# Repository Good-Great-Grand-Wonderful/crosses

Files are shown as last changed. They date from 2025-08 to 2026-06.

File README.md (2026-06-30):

> [!NOTE]
> This repo is for historical purposes. Crosses has iterated and is now on [V2](https://github.com/Good-Great-Grand-Wonderful/crosses-v2)

# Crosses
_DSF2417

### Gerbers

Production ready and prepped with JLCPCB part numbers: [Gerbers](Gerbers)

### BOM

#### Cases

N = Number of trackballs

| Qty |3x5 | 3x6 | 4x6 | Item | Notes |
|---|----|-----|-----|---|---|
| 24 | x  | x | x | M3 Heat set inserts | |
| 16 | x  | x | x | M3 x 5mm Hex Bolts | +2 for every trackball you delete |
| 2xN | x  | x | x | M3 x 12mm Hex Bolts | |
| 2xN | x  | x | x | M3 x 8mm Hex Bolts | |
| 1 | x  | x | x | Thumb Cluster PCB Panel | |
| 4 | x  | x | x | Hirose FH12-14S 0.5SH 1x14 1MP P0.50mm Horizontal | |
| 2 | x  | x | x | SM06B-SRSS-TB(LF)(SN) | |
| 1 | x  | | | 3x5 Matrix PCB Panel | |
| 1 | | x | | 3x6 Matrix PCB Panel | |
| 1 | | | x | 4x6 Matrix PCB Panel | |
| 2 | x  | x | x | 150mm 14p 0.5mm pitch FFC cables | |
| 1xN | x  | x | x | 100mm 6p JST SH 1.0 Same direction cables | |
| 2x | x  | x | x | Thumb Cluster Case (one should be flipped) | |
| 2x | x  | | | 3x5 Matrix Case (one should be flipped) | |
| 2x | | x | | 3x6 Matrix Case (one should be flipped) | |
| 2x | | | x | 4x6 Matrix Case (one should be flipped) | |
| 36x | x  | | | Kailh Choc Hotswap Sockets | |
| 42x | | x | | Kailh Choc Hotswap Sockets | |
| 54x | | | x | Kailh Choc Hotswap Sockets | |
| 36x | x  | | | 1N4148 SMD SOD-123 Resistors | |
| 42x | | x | | 1N4148 SMD SOD-123 Resistors | |
| 54x | | | x | 1N4148 SMD SOD-123 Resistors | |
| 2 | x  | x | x | Trackball Mount | `models` directory |
| 1xN | x  | x | x | Trackball PCB | |
| 1xN | x  | x | x | PMW3610 | |
| 1xN | x  | x | x | Trackball Carrier Base | `models` directory |
| 1xN | x  | x | x | Trackball Carrier Top | `models` directory |

## License



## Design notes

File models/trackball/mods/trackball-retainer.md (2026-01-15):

# Trackball Retainer

## Description
A trackball retainer mod for the Crosses/Bridges keyboards.

## Compatibility
- **Status:** Only tested with the **Bridges** variant.

## Bill of Materials (BOM)
- **Bearings:** 6x 2.8mm diameter bearings.
  - *Note:* 3mm bearings may work but have not been tested.
- **Heat Inserts:** 
  - Hole requires a **4.4mm** diameter heat insert (slightly larger than the standard ones used for Crosses/Bridges).

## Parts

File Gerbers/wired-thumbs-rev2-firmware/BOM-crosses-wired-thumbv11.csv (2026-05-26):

Comment | Designator | Footprint | LCSC | Quantity
SM06B-SRSS-TB(LF)(SN) | J1,J2 | SM06B-SRSS-TB(LF)(SN) | C160405 | 2
TYPE-C-31-M-12 USB | P1,P2 | USB_C_Receptacle_HRO_TYPE-C-31-M-12 | C165948 | 2
Conn_01x14_Pin | J4,J5 | Hirose_FH12-14S-0.5SH_1x14-1MP_P0.50mm_Horizontal | C5378715 | 2
1N4148 | D1,D2,D3,D4,D5,D6 | D_SOD-123 | C81598 | 6
MountingHole | H3 | MountingHole_3.2mm_M3_DIN965_Pad |  | 1
MountingHole | H1 | MountingHole_3.2mm_M3_DIN965_Pad |  | 1
MountingHole | H2 | MountingHole_3.2mm_M3_DIN965_Pad |  | 1

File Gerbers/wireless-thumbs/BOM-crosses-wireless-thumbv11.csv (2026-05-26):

Comment | Designator | Footprint | LCSC | Quantity
SM06B-SRSS-TB(LF)(SN) | J1,J2 | JST_SH_SM06B-SRSS-TB_1x06-1MP_P1.00mm_Horizontal | C160405 | 2
Conn_01x14_Pin | J4,J5 | XUNPU_FPC-05F-14PH20_1x14-1MP_P0.5mm_Horizontal | C2856800 | 2
1N4148 | D1,D2,D3,D4,D5,D6 | D_SOD-123 | C81598 | 6

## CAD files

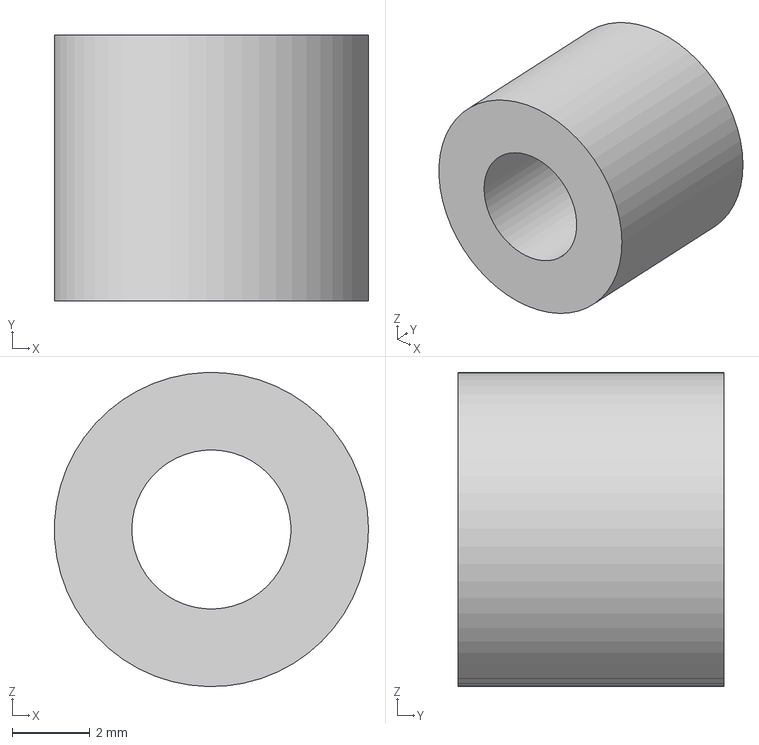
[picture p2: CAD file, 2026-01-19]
models/experiments/adjustable/adjustable-mount-spacer.step
8.09 x 6.86 x 8.10 mm

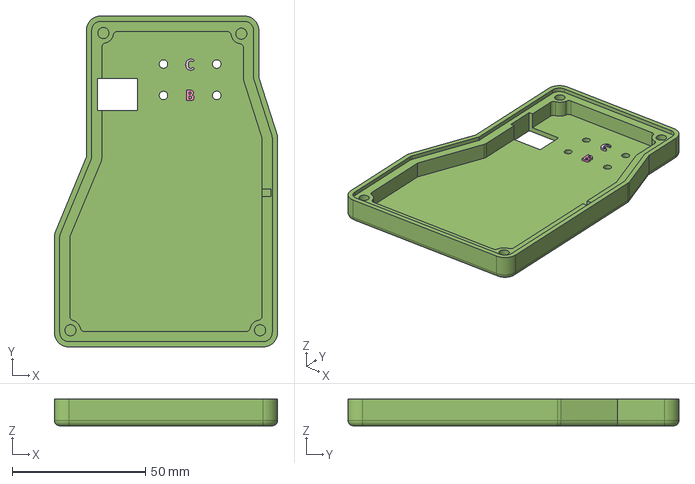
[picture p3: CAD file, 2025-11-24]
models/matrix/MatrixCase-3x6-Right.step
83.8 x 124.3 x 10.0 mm

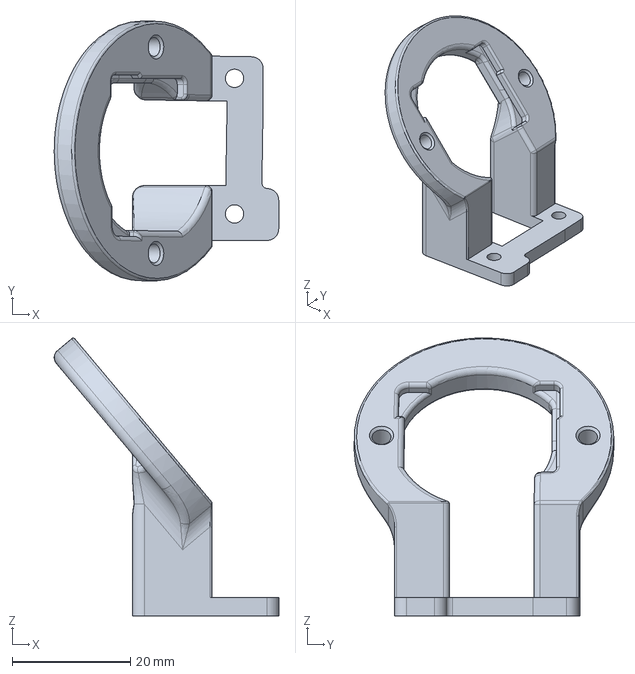
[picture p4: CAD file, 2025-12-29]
models/thumbs/Crosses-Trackball-Mount-Right.step
38.1 x 44.0 x 47.1 mm

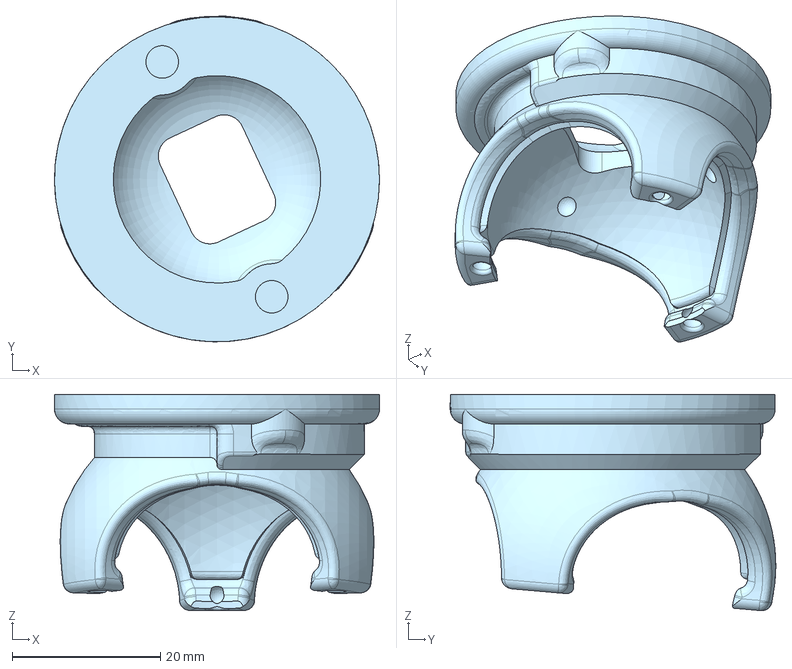
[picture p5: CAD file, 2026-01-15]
models/trackball/mods/trackball-retainer.step
43.9 x 44.0 x 29.2 mm

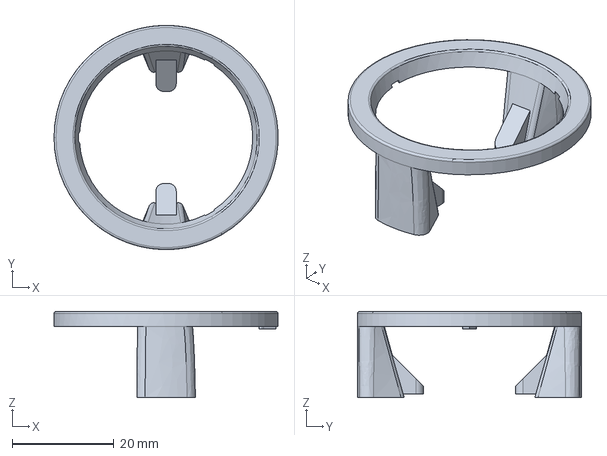
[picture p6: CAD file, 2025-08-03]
models/trackball/Trackball-Top-Static.step
44.0 x 44.0 x 16.9 mm

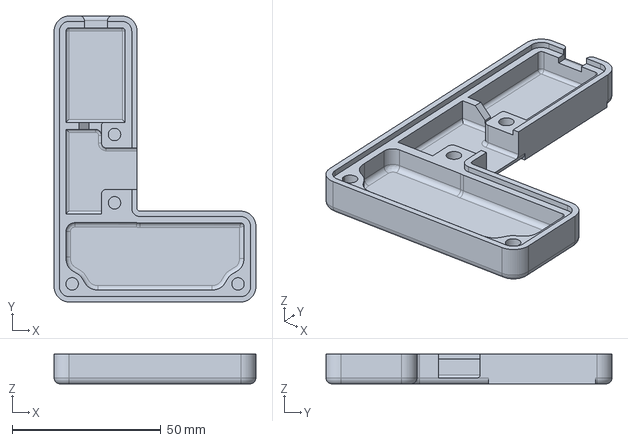
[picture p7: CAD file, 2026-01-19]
models/experiments/adjustable/adjustable-thumb-right.step
67.9 x 96.3 x 10.0 mm

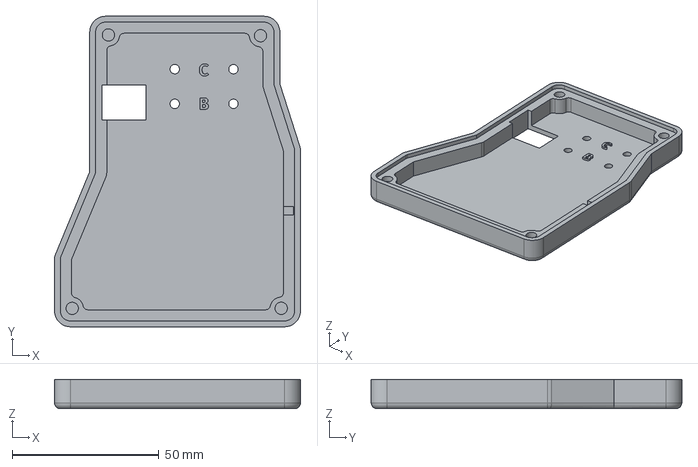
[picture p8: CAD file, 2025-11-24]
models/matrix/MatrixCase-3x5-Right.step
83.8 x 105.8 x 10.0 mm

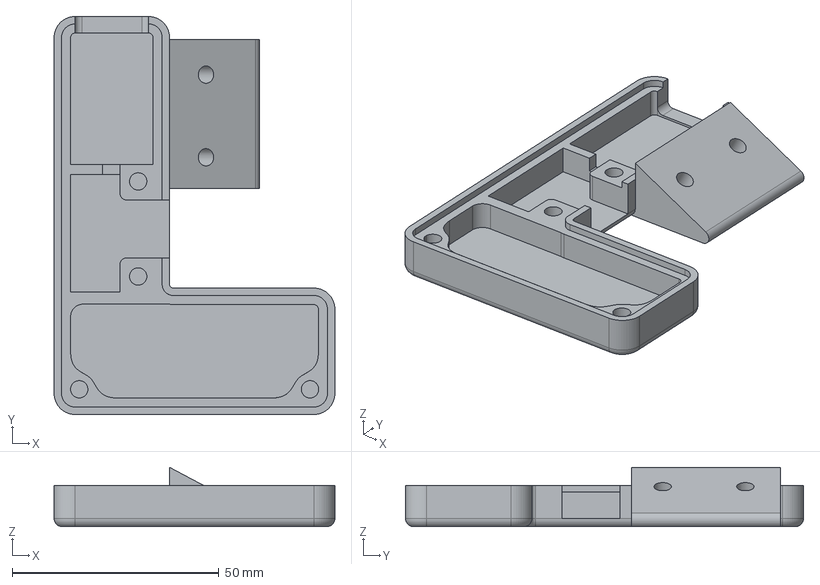
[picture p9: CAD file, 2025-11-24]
models/thumbs/Bridges-Thumbcluster-Right.step
67.9 x 96.3 x 14.4 mm

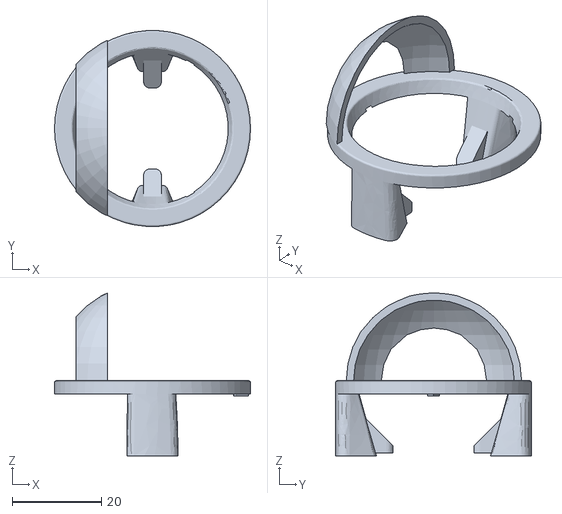
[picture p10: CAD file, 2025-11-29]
models/trackball/mods/Trackball_Top_With_Guard.stl
44.0 x 44.0 x 36.6

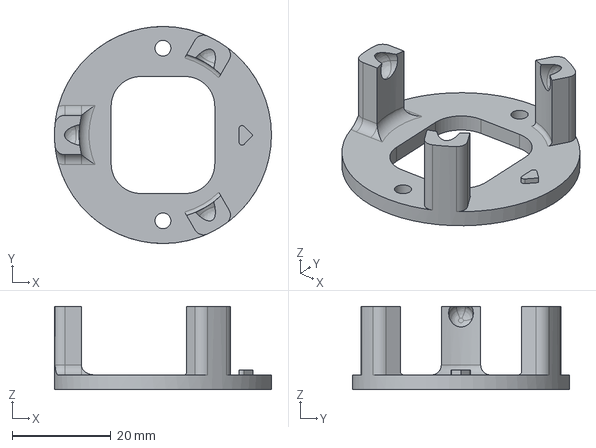
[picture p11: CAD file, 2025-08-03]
models/trackball/Trackball-Base-Static.step
44.0 x 44.0 x 16.9 mm

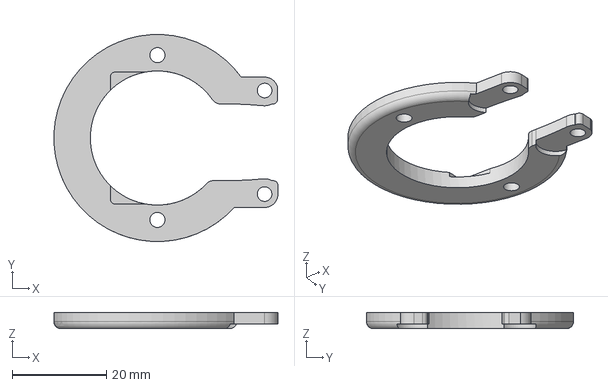
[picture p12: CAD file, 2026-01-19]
models/experiments/adjustable/adjustable-trackball-sensor-base-right.step
47.6 x 43.9 x 3.50 mm

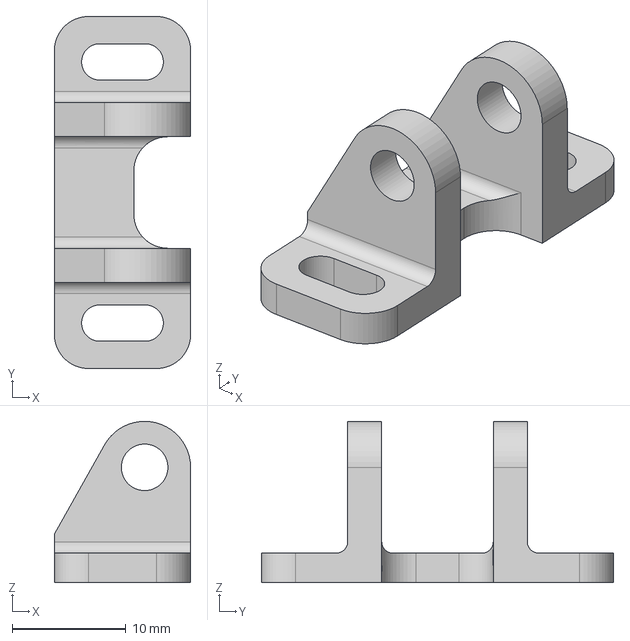
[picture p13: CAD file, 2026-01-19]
models/experiments/adjustable/adjustable-thumb-mount-right.step
12.0 x 31.0 x 14.2 mm

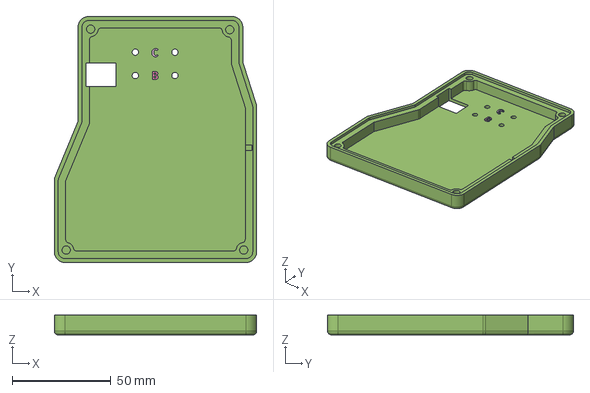
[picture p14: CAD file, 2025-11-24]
models/matrix/MatrixCase-4x6-Right.step
102.3 x 124.3 x 10.0 mm

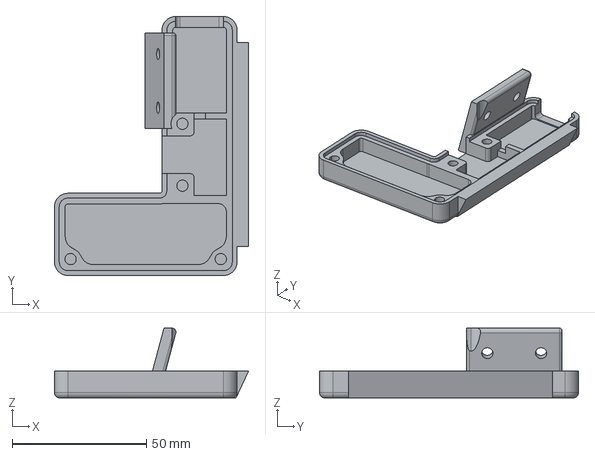
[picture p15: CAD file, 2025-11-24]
models/thumbs/Crosses-Thumbcluster-Left.step
72.2 x 96.3 x 26.0 mm

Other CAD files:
models/matrix/MatrixCase-3x6-Left.step
models/thumbs/Bridges-Thumbcluster-Left.step
models/experiments/adjustable/adjustable-matrix-mount-right.step
models/matrix/MatrixCase-4x6-Left.step
models/experiments/adjustable/adjustable-matrix-42-right.step
models/experiments/adjustable/adjustable-trackball-mount-right.step
models/matrix/MatrixCase-3x5-Left.step
models/thumbs/Bridges-Trackball-Mount-Left.step
models/thumbs/Bridges-Trackball-Mount-Right.step
models/thumbs/Crosses-Thumbcluster-Right.step
models/thumbs/Crosses-Trackball-Mount-Left.step

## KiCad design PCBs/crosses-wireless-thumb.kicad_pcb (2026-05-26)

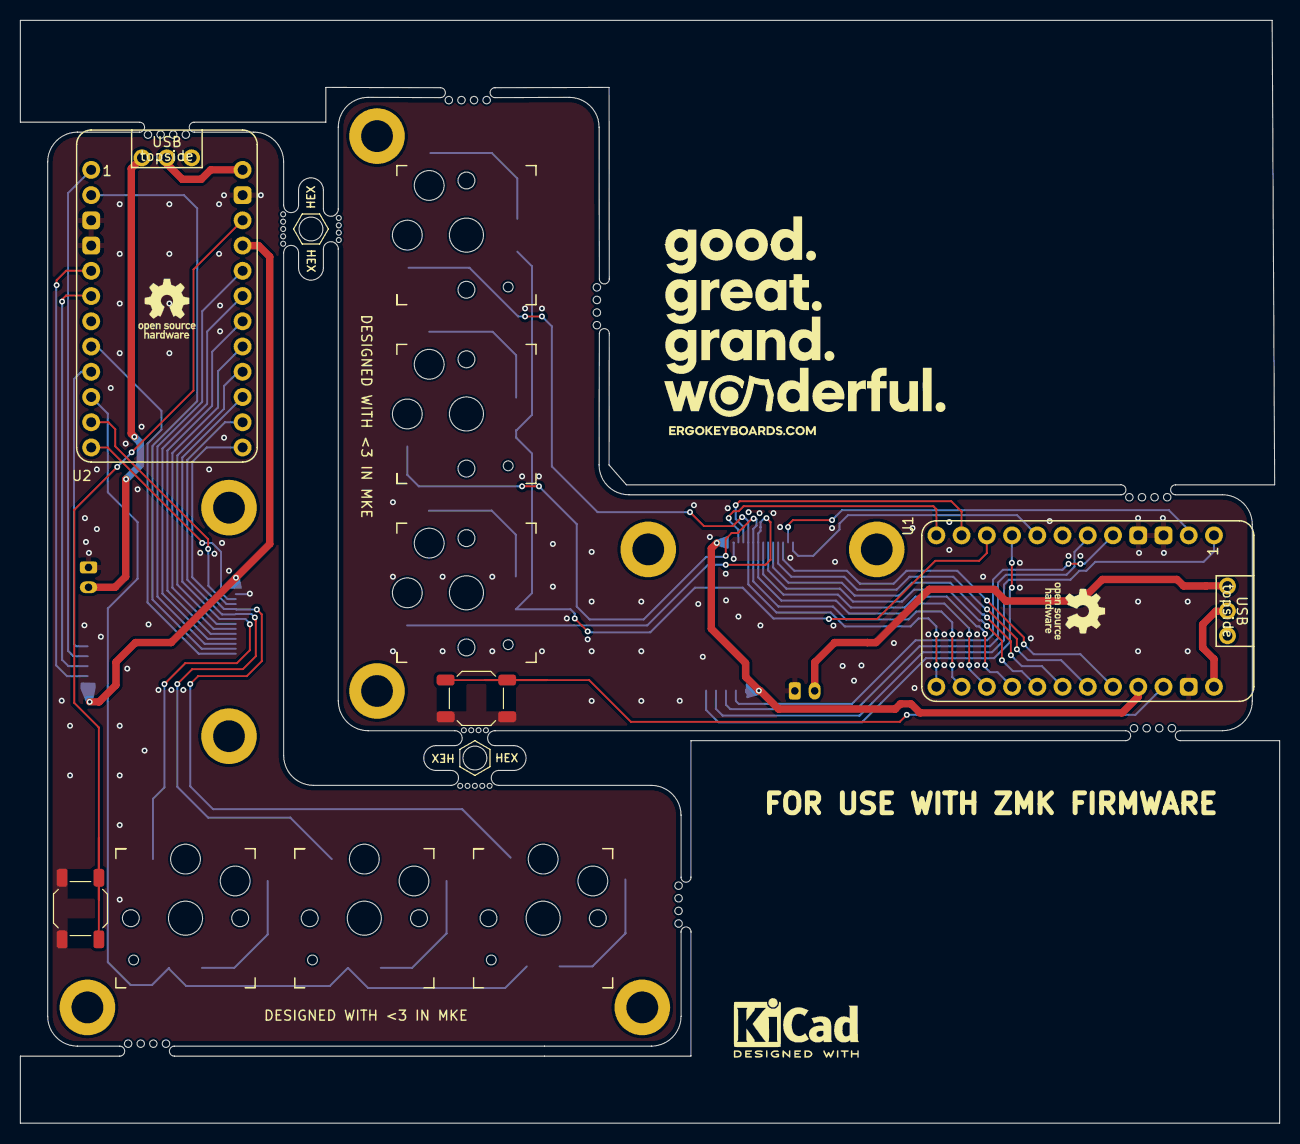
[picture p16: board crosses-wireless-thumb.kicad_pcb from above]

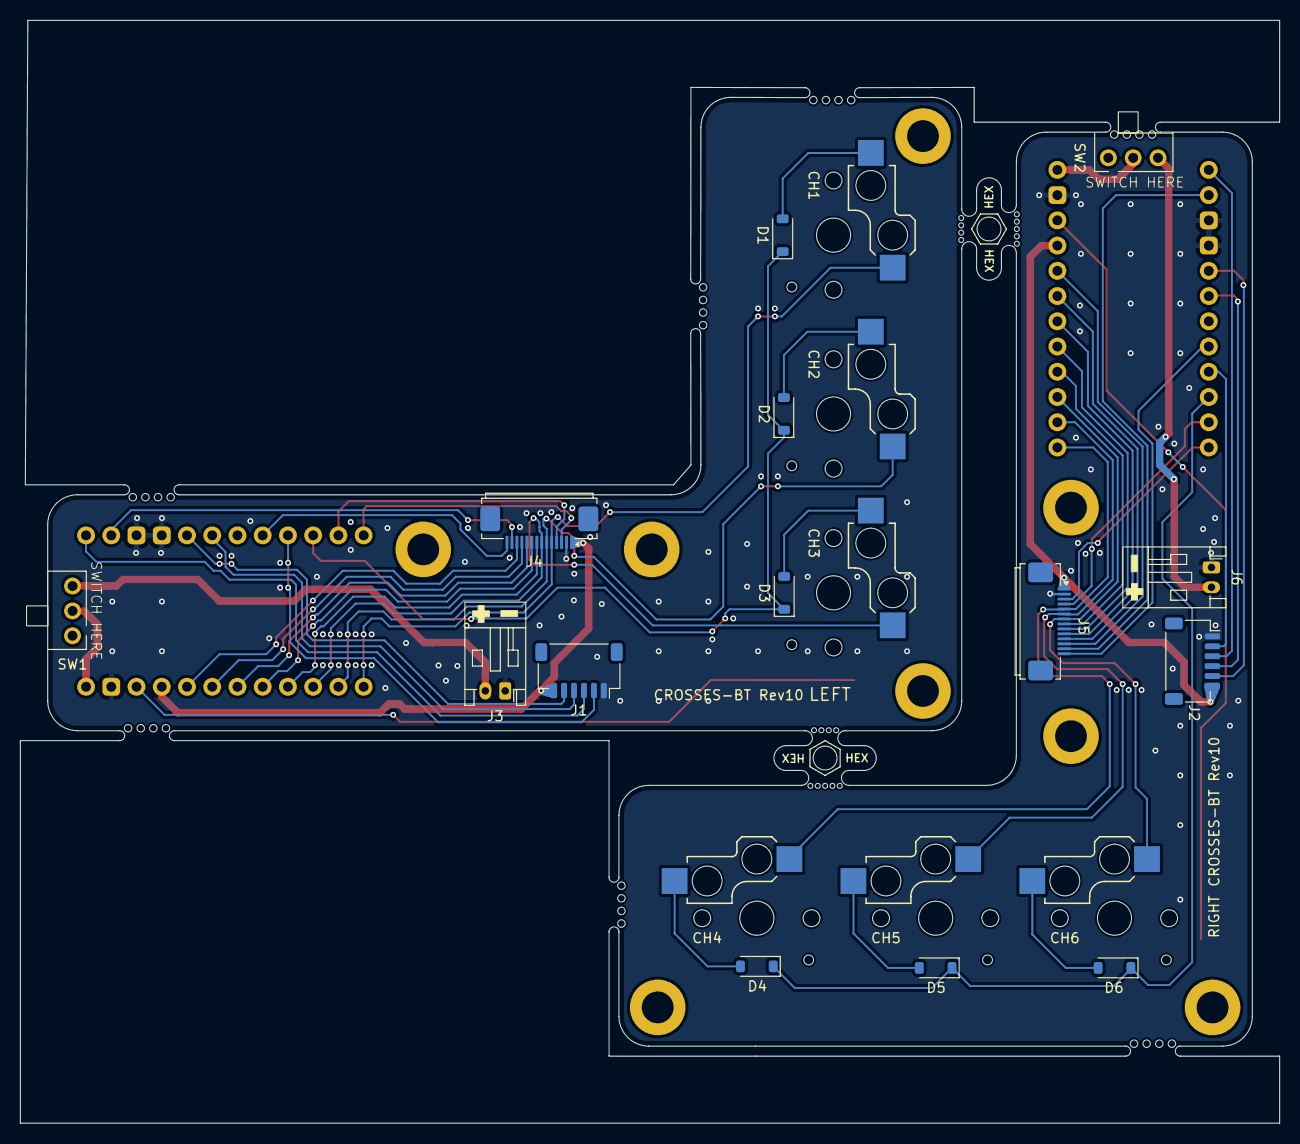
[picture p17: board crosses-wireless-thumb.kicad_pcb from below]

Board: 2 copper layers, 126.8 x 111.0 mm, 34 parts (18 on the bottom side), 49 nets.

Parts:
CH1, CH2, CH3, CH4, CH5, CH6: CPG135001S30; Kailh_socket_PG1350
D1, D2, D3, D4, D5, D6: 1N4148; D_SOD-123
H1, H1#2, H2, H2#2, H3, H3#2, H3#3, H3#4: MountingHole; MountingHole_3.2mm_M3_DIN965_Pad
J1, J2: SM06B-SRSS-TB(LF)(SN); JST_SH_SM06B-SRSS-TB_1x06-1MP_P1.00mm_Horizontal
J3, J6: Conn_01x02_Socket; JST_PH_S2B-PH-K_1x02_P2.00mm_Horizontal
J4, J5: Conn_01x14_Pin; XUNPU_FPC-05F-14PH20_1x14-1MP_P0.5mm_Horizontal
MB5, MB5#2: 5.5mm; mousebites_5p5mm_easysnap
SW1, SW2: SW_SPDT; Switch-MK-12D18-G030
SW3, SW4: SW_SPST; SW_SPST_SKQG_WithStem
U1, U2: supermini nrf / nice nano v2; Helios_AH_USBup

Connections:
GND: J1.1, J2.1, J3.1, J4.2, J5.2, J6.1, SW3.1 (A), SW4.2 (B), U1.3 (GND), U1.4 (GND), U1.14 (GND), U2.3 (GND), U2.4 (GND), U2.14 (GND)
L-COL0: J4.9, U1.20 (F7)
L-COL1: J4.8, U1.21 (B1)
L-COL2: CH1.1, J4.5, U1.24 (B6)
L-COL3: CH2.1, J4.6, U1.23 (B2)
L-COL4: CH3.1, J4.7, U1.22 (B3)
L-COLP: J4.13, U1.2 (D2-RX)
L-CS: J1.2, U1.9 (D7)
L-I2C SCL: J4.3, U1.12 (B5)
L-I2C SDA: J4.4, U1.11 (B4)
L-MISO: J1.3, U1.1 (D3-TX)
L-MOSI: J1.4, U1.6 (D0)
L-ROW0: J4.10, U1.19 (F6)
L-ROW1: J4.11, U1.18 (F5)
L-ROW2: J4.12, U1.17 (F4)
L-ROW3: D1.1 (K), D2.1 (K), D3.1 (K), U1.10 (E6)
L-ROWH: J4.14, U1.8 (C6)
L-RST: SW3.2 (B), U1.15 (RST)
L-SCK: J1.5, U1.5 (D1)
L-VCC: J1.6, J4.1, U1.16 (VCC)
unnamed: CH1.2, D1.2 (A)
unnamed: CH2.2, D2.2 (A)
unnamed: CH3.2, D3.2 (A)
unnamed: CH4.2, D4.2 (A)
unnamed: CH5.2, D5.2 (A)
unnamed: CH6.2, D6.2 (A)
unnamed: J3.2, SW1.3 (C)
unnamed: J6.2, SW2.3 (C)
R-COL0: J5.9, U2.20 (F7)
R-COL1: J5.8, U2.21 (B1)
R-COL2: CH4.1, J5.5, U2.24 (B6)
R-COL3: CH5.1, J5.6, U2.23 (B2)
R-COL4: CH6.1, J5.7, U2.22 (B3)
R-COLP: J5.13, U2.2 (D2-RX)
R-CS: J2.2, U2.9 (D7)
R-I2C SCL: J5.3, U2.12 (B5)
R-I2C SDA: J5.4, U2.11 (B4)
R-MISO: J2.3, U2.1 (D3-TX)
R-MOSI: J2.4, U2.6 (D0)
R-ROW0: J5.10, U2.19 (F6)
R-ROW1: J5.11, U2.18 (F5)
R-ROW2: J5.12, U2.17 (F4)
R-ROW3: D4.1 (K), D5.1 (K), D6.1 (K), U2.10 (E6)
R-ROWH: J5.14, U2.8 (C6)
R-RST: SW4.1 (A), U2.15 (RST)
R-SCK: J2.5, U2.5 (D1)
R-VCC: J2.6, J5.1, U2.16 (VCC)
VBATTL: SW1.2 (B), U1.13 (B0)
VBATTR: SW2.2 (B), U2.13 (B0)

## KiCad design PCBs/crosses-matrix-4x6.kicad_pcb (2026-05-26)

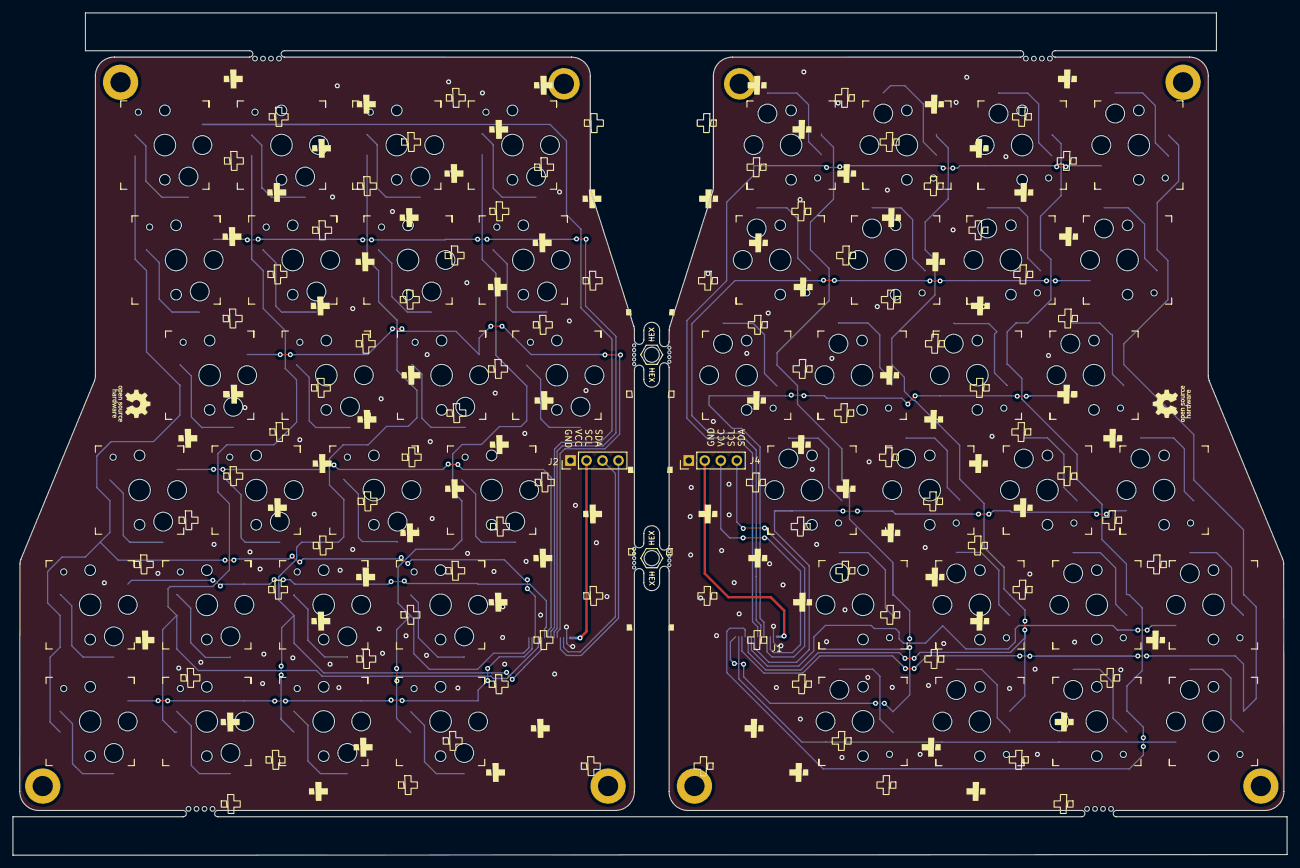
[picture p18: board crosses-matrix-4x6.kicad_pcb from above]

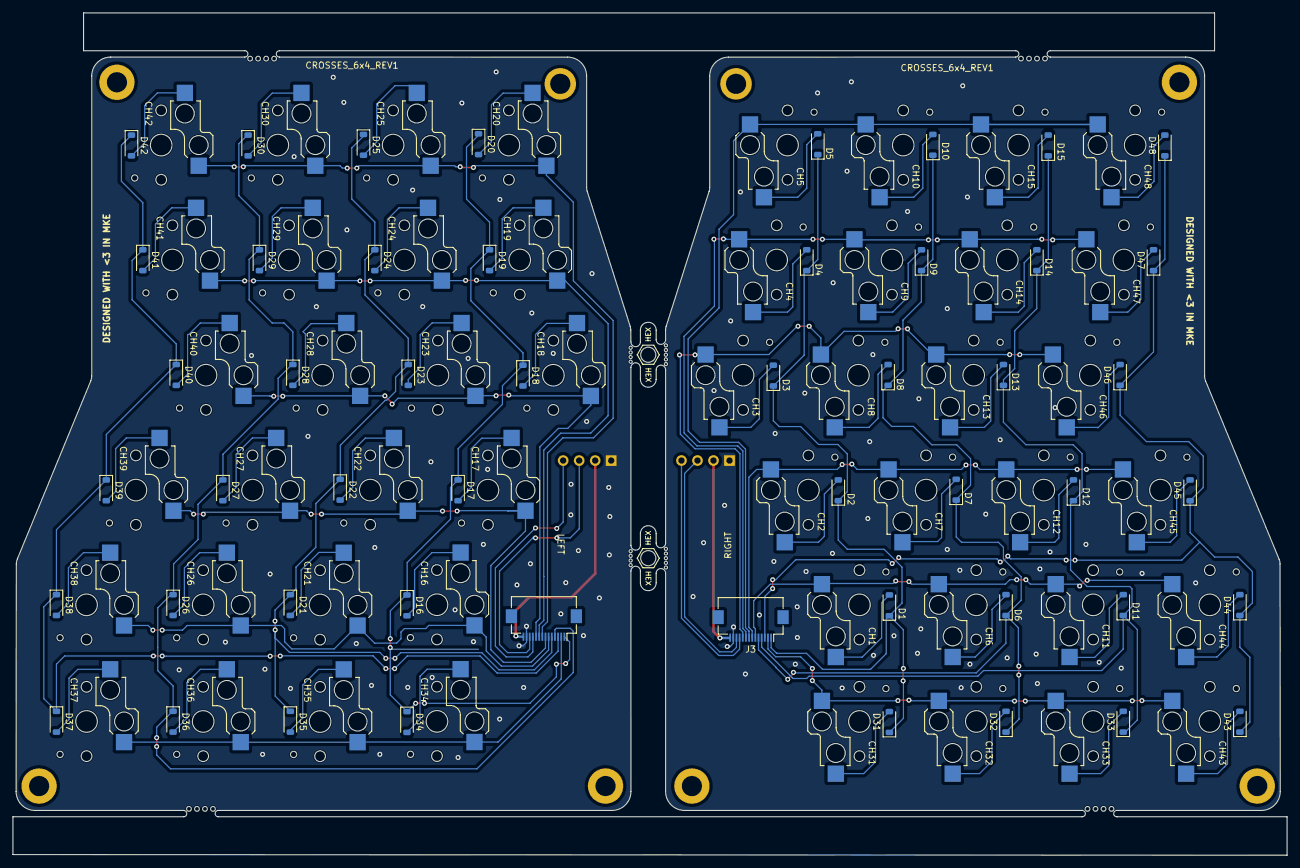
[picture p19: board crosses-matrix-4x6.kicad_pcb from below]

Board: 2 copper layers, 202.1 x 133.6 mm, 110 parts (54 on the bottom side), 75 nets.

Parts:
CH1, CH2, CH3, CH4, CH5, CH6, CH7, CH8, CH9, CH10, CH11, CH12, CH13, CH14, CH15, CH16, CH17, CH18, CH19, CH20, CH21, CH22, CH23, CH24, CH25, CH26, CH27, CH28, CH29, CH30, CH31, CH32, CH33, CH34, CH35, CH36, CH37, CH38, CH39, CH40, CH41, CH42, CH43, CH44, CH45, CH46, CH47, CH48: CPG135001S30; Kailh_socket_PG1350
D1, D2, D3, D4, D5, D6, D7, D8, D9, D10, D11, D12, D13, D14, D15, D16, D17, D18, D19, D20, D21, D22, D23, D24, D25, D26, D27, D28, D29, D30, D31, D32, D33, D34, D35, D36, D37, D38, D39, D40, D41, D42, D43, D44, D45, D46, D47, D48: 1N4148; D_SOD-123
H1, H1#2, H3, H3#2, H5, H5#2, H6, H6#2: MountingHole; MountingHole_3.2mm_M3_DIN965_Pad
J1, J3: Conn_01x14_Pin; Hirose_FH12-14S-0.5SH_1x14-1MP_P0.50mm_Horizontal
J2, J4: Conn_01x04_Socket; PinHeader_1x04_P2.54mm_Vertical
MB5, MB5#2: 5.5mm; mousebites_5p5mm_easysnap

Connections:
GND: J1.13, J2.1, J3.13, J4.1
L-COL0: CH1.1, CH6.1, CH11.1, CH44.1, J3.6
L-COL1: CH2.1, CH7.1, CH12.1, CH45.1, J3.7
L-COL2: CH3.1, CH8.1, CH13.1, CH46.1, J3.10
L-COL3: CH4.1, CH9.1, CH14.1, CH47.1, J3.9
L-COL4: CH5.1, CH10.1, CH15.1, CH48.1, J3.8
L-COLP: CH31.1, CH32.1, CH33.1, CH43.1, J3.2
L-ROW0: D6.1 (K), D7.1 (K), D8.1 (K), D9.1 (K), D10.1 (K), D32.1 (K), J3.5
L-ROW1: D11.1 (K), D12.1 (K), D13.1 (K), D14.1 (K), D15.1 (K), D33.1 (K), J3.4
L-ROW2: D43.1 (K), D44.1 (K), D45.1 (K), D46.1 (K), D47.1 (K), D48.1 (K), J3.3
L-ROW-N1: D1.1 (K), D2.1 (K), D3.1 (K), D4.1 (K), D5.1 (K), D31.1 (K), J3.1
unnamed: CH1.2, D1.2 (A)
unnamed: CH2.2, D2.2 (A)
unnamed: CH3.2, D3.2 (A)
unnamed: CH4.2, D4.2 (A)
unnamed: CH5.2, D5.2 (A)
unnamed: CH6.2, D6.2 (A)
unnamed: CH7.2, D7.2 (A)
unnamed: CH8.2, D8.2 (A)
unnamed: CH9.2, D9.2 (A)
unnamed: CH10.2, D10.2 (A)
unnamed: CH11.2, D11.2 (A)
unnamed: CH12.2, D12.2 (A)
unnamed: CH13.2, D13.2 (A)
unnamed: CH14.2, D14.2 (A)
unnamed: CH15.2, D15.2 (A)
unnamed: CH16.2, D16.2 (A)
unnamed: CH17.2, D17.2 (A)
unnamed: CH18.2, D18.2 (A)
unnamed: CH19.2, D19.2 (A)
unnamed: CH20.2, D20.2 (A)
unnamed: CH21.2, D21.2 (A)
unnamed: CH22.2, D22.2 (A)
unnamed: CH23.2, D23.2 (A)
unnamed: CH24.2, D24.2 (A)
unnamed: CH25.2, D25.2 (A)
unnamed: CH26.2, D26.2 (A)
unnamed: CH27.2, D27.2 (A)
unnamed: CH28.2, D28.2 (A)
unnamed: CH29.2, D29.2 (A)
unnamed: CH30.2, D30.2 (A)
unnamed: CH31.2, D31.2 (A)
unnamed: CH32.2, D32.2 (A)
unnamed: CH33.2, D33.2 (A)
unnamed: CH34.2, D34.2 (A)
unnamed: CH35.2, D35.2 (A)
unnamed: CH36.2, D36.2 (A)
unnamed: CH37.2, D37.2 (A)
unnamed: CH38.2, D38.2 (A)
unnamed: CH39.2, D39.2 (A)
unnamed: CH40.2, D40.2 (A)
unnamed: CH41.2, D41.2 (A)
unnamed: CH42.2, D42.2 (A)
unnamed: CH43.2, D43.2 (A)
unnamed: CH44.2, D44.2 (A)
unnamed: CH45.2, D45.2 (A)
unnamed: CH46.2, D46.2 (A)
unnamed: CH47.2, D47.2 (A)
unnamed: CH48.2, D48.2 (A)
R-COL0: CH16.1, CH21.1, CH26.1, CH38.1, J1.6
R-COL1: CH17.1, CH22.1, CH27.1, CH39.1, J1.7
R-COL2: CH18.1, CH23.1, CH28.1, CH40.1, J1.10
R-COL3: CH19.1, CH24.1, CH29.1, CH41.1, J1.9
R-COL4: CH20.1, CH25.1, CH30.1, CH42.1, J1.8
R-COLP: CH34.1, CH35.1, CH36.1, CH37.1, J1.2
R-ROW0: D21.1 (K), D22.1 (K), D23.1 (K), D24.1 (K), D25.1 (K), D35.1 (K), J1.5
R-ROW1: D26.1 (K), D27.1 (K), D28.1 (K), D29.1 (K), D30.1 (K), D36.1 (K), J1.4
R-ROW2: D37.1 (K), D38.1 (K), D39.1 (K), D40.1 (K), D41.1 (K), D42.1 (K), J1.3
R-ROW-N1: D16.1 (K), D17.1 (K), D18.1 (K), D19.1 (K), D20.1 (K), D34.1 (K), J1.1
SCL: J2.3, J3.12
SCL-R: J1.12, J4.3
SDA: J2.4, J3.11
SDA-R: J1.11, J4.4
VCC: J2.2, J3.14
VCC-R: J1.14, J4.2

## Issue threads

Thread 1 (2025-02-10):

publish flipped models

RudolfVonKrugstein, 2025-02-10:
Would it be possible to publish the flipped versions of those step files that need flipping?
Or provide instructions on how to do it?

Because I have no Idea :).

vinniefranco, 2025-02-13:
Hi there!

I can publish them if needed, but here as the stepsto flip a model in Orca Slicer:

1. Import step file
2. Right click on object
3. Select "Clone" to make a copy
4. Right click on clone
5. Select "Mirror -> Along X axis"

Done!

RudolfVonKrugstein, 2025-02-14:
Ah, that worked! Thank you!

Closed 2025-02-14.

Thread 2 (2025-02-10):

missing trackball base and top

RudolfVonKrugstein, 2025-02-10:
The following parts are missing, or?

- Trackball Carrier Base  
- Trackball Carrier Top

Or am I not seeing something?

vinniefranco, 2025-02-13:
Yup! I'm still working through the documentation. But, the trackball is it's own repo. You'll find the models and PCBs there: https://github.com/Good-Great-Grand-Wonderful/PMW3360DM-T2QU

Closed 2025-02-13.

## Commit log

2025-08-03 Adding trackball models
    Adding static carrier
    [Trackball-Base-Static.step, Trackball-Top-Static.step]
2025-09-14 Tweaking thumbcluster
    [Crosses-Trackball-Mount.step]
2025-09-28 Crosses trackball mount fine tuning
    [Crosses-Trackball-Mount.step]
2025-10-02 Adding wireless thumb cases
    [Bridges-Wireless-Thumbcluster.step, Crosses-Wireless-Thumbcluster.step]
2025-10-03 Update README.md
    Change mentions from 3mm to M3
2025-11-11 No modifications needed for wireless
    [Bridges-Wireless-Thumbcluster.step, Crosses-Wireless-Thumbcluster.step]
2025-11-24 Better geometry for trackball mount
    [Crosses-Trackball-Mount.step]
2025-11-24 Improve bridges trackball mount
    [Bridges-Trackball-Mount.step]
2025-11-24 Adding explicit left/right models
    [Bridges-Trackball-Mount-Left.step, Bridges-Trackball-Mount-Right.step, Crosses-Trackball-Mount-Left.step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]
2025-11-24 Explicit left/right thumbclusters
    [Bridges-Thumbcluster-Left.step, Bridges-Thumbcluster-Right.step, Crosses-Thumbcluster-Left.step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]
2025-11-24 Update FFC cables and trackball components in README
2025-11-27 Add small spherical guard to stop excess movement.
    Harder to print, and somewhat fragile until a trackball is inserted.
    Inserting a trackball only takes a small push, no risk of damage.
    [Trackball_Top_With_Guard.stl]
2025-11-29 Move the trackball guard stl file to a mod folder.
    At the request of the primary author, this commit moves the trackball
    guard file to a new folder that distinguishes this as a modificatiohn to
    the originaal desgn.
    [Trackball_Top_With_Guard.stl]
2025-12-29 Adding clearance on right mount
    [Crosses-Trackball-Mount-Right.step]
2026-01-15 feat: Introduce trackball retainer mod with documentation and 3D model for Crosses/Bridges keyboards.
    [trackball-retainer.step]
2026-01-19 Adding adjustable experiment
    [adjustable-matrix-42-right.step, adjustable-matrix-mount-right.step, adjustable-mount-spacer.step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]
2026-03-19 Fixup old release
    [crosses-wired-thumb-cluster.kicad_pcb, crosses-wired-thumbv11-wireless-test.kicad_pcb]
2026-05-26 Changing license, adding wireless Gerbers, PCBs, etc
    [BOM-crosses-wired-thumb.csv, BOM-crosses-wired-thumbv11.csv, BOM-crosses-wireless-thumbv11.csv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]

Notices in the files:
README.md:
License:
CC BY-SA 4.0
